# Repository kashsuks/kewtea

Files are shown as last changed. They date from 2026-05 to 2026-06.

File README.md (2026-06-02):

# kewtea
A 30% low profile ortholinear keyboard.

I've recently found that normal keyboards just have too much going on, so it's time to make things simple.



## Bill of Materials

| Name | Quantity | Purpose | Link | Cost (CAD) | Cost (USD) |
|---|---|---|---|---|---|
| Kailh Choc Low Profile Switches (set of 10) | 3 | Switches for the keys | https://typeractive.xyz/products/choc-switches?variant=51038935122151 | 24.00 | 17.40 |
| DO-35 Diodes (set of 50) | 1 | Diodes for the keys grid | https://www.aliexpress.com/item/1005006711895793.html | 3.89 | 2.82 |
| 0.91 Inch 128x32 I2C OLED Display | 1 | OLED display | https://www.aliexpress.com/item/1005008640132638.html | 3.27 | 2.37 |
| Pro Micro NRF52840 | 1 | Cheaper alternative to nice!nano v2 mcu | https://www.aliexpress.com/item/1005009026511947.html | 5.67 | 4.11 |
| MBK Choc Keycaps (set of 10) | 3 | Keycaps needed for the switches | https://typeractive.xyz/products/mbk-keycaps | 15.00 | 10.87 |
| JLCPCB PCB Manufacturing | 1 | The actual pcb board | https://jlcpcb.com/ | N/A | 10.02 |
## Code

I used [kmk](https://github.com/KMKfw/kmk_firmware) along with the circuitpython Nice!nano `.UF2`. They can be used interchangeably with the Pro Micro NRF52840 since it's based off the nice!nano.

The code is yet to be thoroughly tested and will be done so after recieving the board :)

## Schematic



## PCB




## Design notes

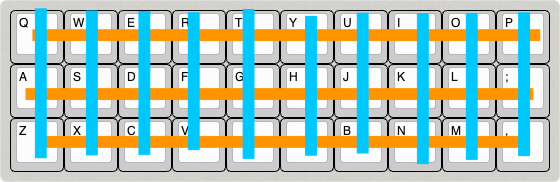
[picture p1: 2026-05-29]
assets/layout.png

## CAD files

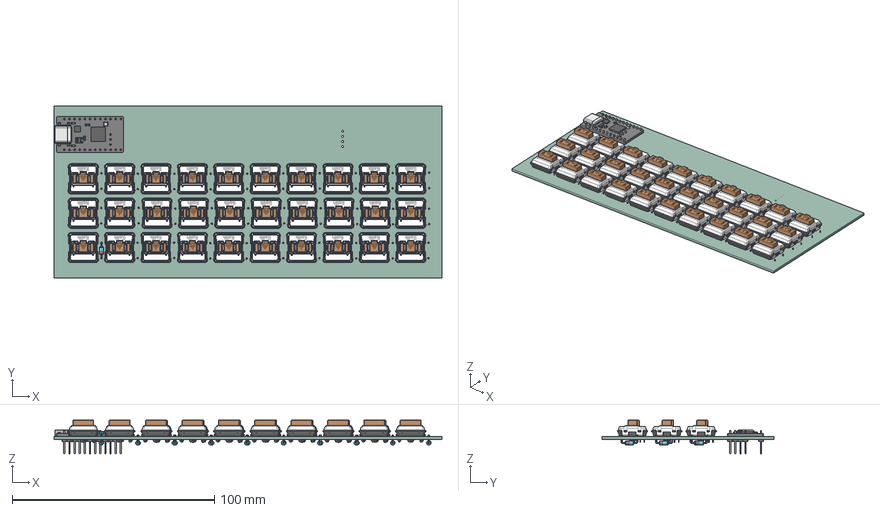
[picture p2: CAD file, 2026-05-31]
kewtea/kewtea.step
192.0 x 85.0 x 16.6 mm
SW_Kailh_Choc_V1_cp x 30
D_DO-35_SOD27_P7.62mm_Horizontal x 30
PinHeader_1x12_P2.54mm_Vertical.step
User Library-TYPE-C-31-M-14.step
MICRO_603 resistor 102
MICRO_stackable header pin x 12
MICRO_stackable header 12
micro_crystal 5x3
MICRO_led
micro_MIC5219
kewtea_PCB

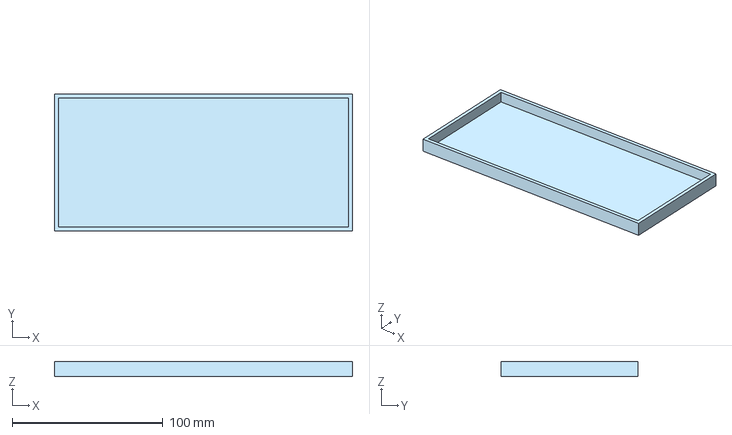
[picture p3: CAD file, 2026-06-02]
production/step/kewtea_case.step
198.0 x 91.0 x 10.0 mm

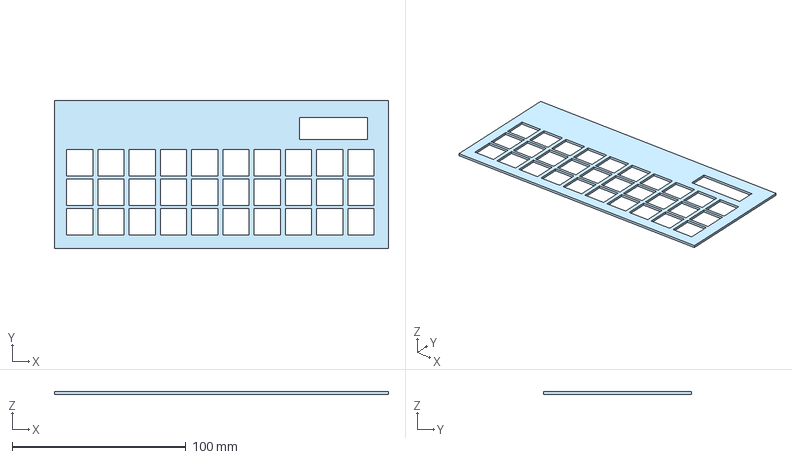
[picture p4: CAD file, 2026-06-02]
production/step/kewtea_plate.step
192.4 x 85.4 x 1.50 mm

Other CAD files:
kewtea/.step
production/stl/kewtea_case.stl
production/stl/kewtea_plate.stl

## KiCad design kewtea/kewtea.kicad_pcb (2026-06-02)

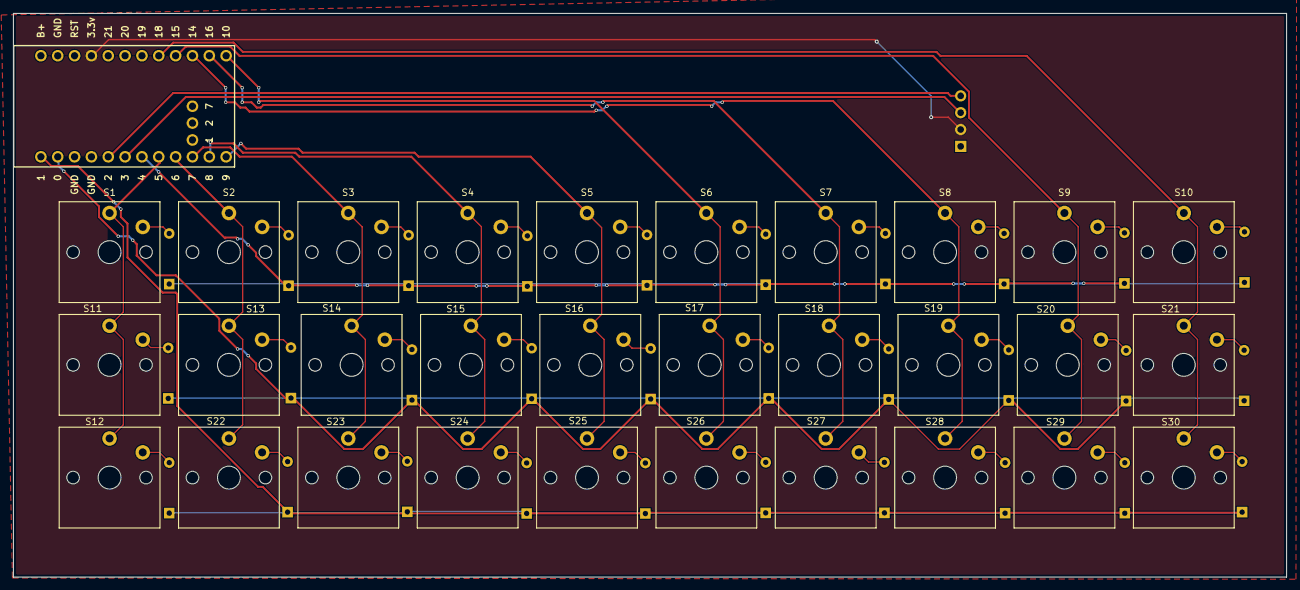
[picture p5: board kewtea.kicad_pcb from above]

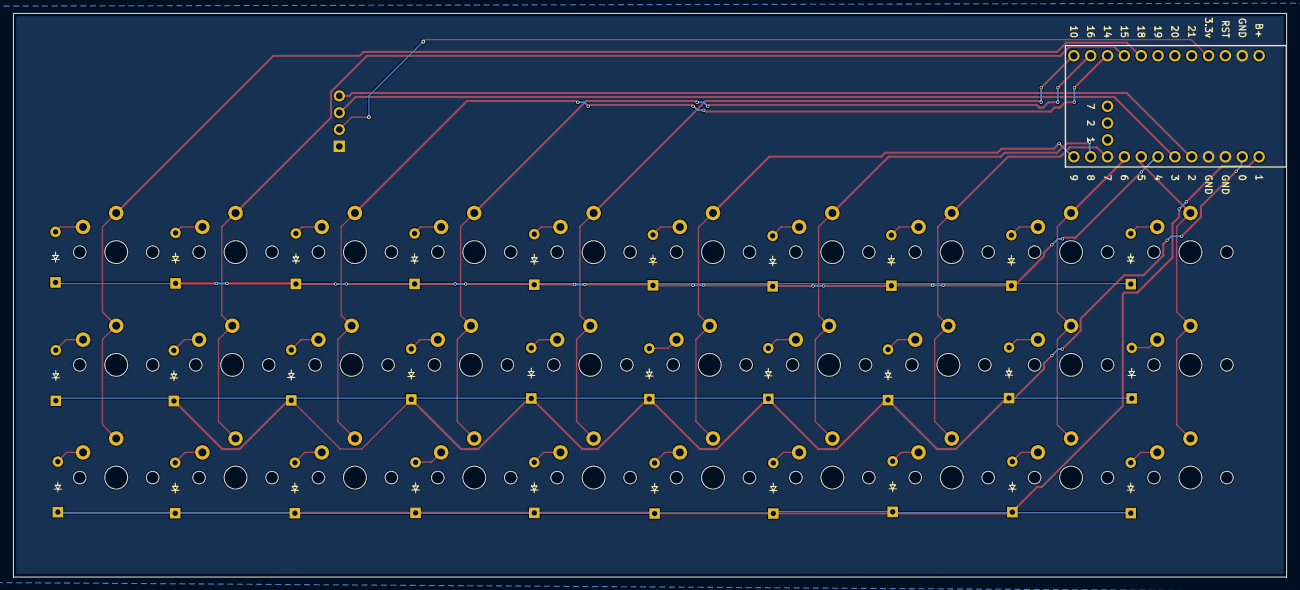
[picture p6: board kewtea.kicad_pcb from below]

Board: 2 copper layers, 192.0 x 85.0 mm, 62 parts (30 on the bottom side), 47 nets.

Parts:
D1, D2, D3, D4, D5, D6, D7, D8, D9, D10, D11, D12, D13, D14, D15, D16, D17, D18, D19, D20, D21, D22, D23, D24, D25, D26, D27, D28, D29, D30: Diode_DO-35
J1: OLED_128x32
S1, S2, S3, S4, S5, S6, S7, S8, S9, S10, S11, S12, S13, S14, S15, S16, S17, S18, S19, S20, S21, S22, S23, S24, S25, S26, S27, S28, S29, S30: Choc_V1
U1: Nice_Nano_V2

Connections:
COL0: S1.1, S11.1, S12.1, U1.8 (5)
COL1: S2.1, S13.1, S22.1, U1.9 (6)
COL2: S3.1, S14.1, S23.1, U1.10 (7)
COL3: S4.1, S15.1, S24.1, U1.11 (8)
COL4: S5.1, S16.1, S25.1, U1.12 (9)
COL5: S6.1, S17.1, S26.1, U1.13 (10)
COL6: S7.1, S18.1, S27.1, U1.14 (16)
COL7: S8.1, S19.1, S28.1, U1.15 (14)
COL8: S9.1, S20.1, S29.1, U1.16 (15)
COL9: S10.1, S21.1, S30.1, U1.17 (18)
GND: J1.1 (GND), U1.3 (GND), U1.4 (GND), U1.23 (GND)
unnamed: D1.2 (A), S1.2
unnamed: D2.2 (A), S2.2
unnamed: D3.2 (A), S3.2
unnamed: D4.2 (A), S4.2
unnamed: D5.2 (A), S5.2
unnamed: D6.2 (A), S6.2
unnamed: D7.2 (A), S7.2
unnamed: D8.2 (A), S8.2
unnamed: D9.2 (A), S9.2
unnamed: D10.2 (A), S10.2
unnamed: D11.2 (A), S11.2
unnamed: D12.2 (A), S12.2
unnamed: D13.2 (A), S13.2
unnamed: D14.2 (A), S14.2
unnamed: D15.2 (A), S15.2
unnamed: D16.2 (A), S16.2
unnamed: D17.2 (A), S17.2
unnamed: D18.2 (A), S18.2
unnamed: D19.2 (A), S19.2
unnamed: D20.2 (A), S20.2
unnamed: D21.2 (A), S21.2
unnamed: D22.2 (A), S22.2
unnamed: D23.2 (A), S23.2
unnamed: D24.2 (A), S24.2
unnamed: D25.2 (A), S25.2
unnamed: D26.2 (A), S26.2
unnamed: D27.2 (A), S27.2
unnamed: D28.2 (A), S28.2
unnamed: D29.2 (A), S29.2
unnamed: D30.2 (A), S30.2
ROW0: D1.1 (K), D2.1 (K), D3.1 (K), D4.1 (K), D5.1 (K), D6.1 (K), D7.1 (K), D8.1 (K), D9.1 (K), D10.1 (K), U1.7 (4)
ROW1: D11.1 (K), D13.1 (K), D14.1 (K), D15.1 (K), D16.1 (K), D17.1 (K), D18.1 (K), D19.1 (K), D20.1 (K), D21.1 (K), U1.2 (0)
ROW2: D12.1 (K), D22.1 (K), D23.1 (K), D24.1 (K), D25.1 (K), D26.1 (K), D27.1 (K), D28.1 (K), D29.1 (K), D30.1 (K), U1.1
SCL: J1.3 (SCL), U1.6 (3)
SDA: J1.4 (SDA), U1.5 (2)
VCC: J1.2 (VCC), U1.21 (3.3v)

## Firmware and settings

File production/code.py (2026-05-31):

"""
code.py — KMK firmware entry point for the kewtea keyboard.

Targets a Pro Micro NRF52840 (nice!nano-compatible) running CircuitPython.
Defines the 3×10 key matrix, single-layer QWERTY keymap, and an SSD1306
OLED that displays elapsed uptime. No build step required — edit this file
directly on the CIRCUITPY USB drive and the changes take effect on save.

Required libraries (copy to CIRCUITPY/lib/ from the Adafruit bundle):
  - adafruit_displayio_ssd1306
  - adafruit_display_text
"""

import time
import busio
import displayio
import terminalio
import microcontroller
from adafruit_display_text import label
import adafruit_displayio_ssd1306

from kmk.kmk_keyboard import KMKKeyboard
from kmk.keys import KC
from kmk.scanners import DiodeOrientation


# ── Display ───────────────────────────────────────────────────────────────────

displayio.release_displays()

_i2c = busio.I2C(
    scl=microcontroller.pin.P0_20,  # header pin 6
    sda=microcontroller.pin.P0_17,  # header pin 5
)
_bus = displayio.I2CDisplay(_i2c, device_address=0x3C)
_display = adafruit_displayio_ssd1306.SSD1306(_bus, width=128, height=32)

_root = displayio.Group()
_display.root_group = _root

_time_label = label.Label(
    terminalio.FONT,
    text='00:00:00',
    color=0xFFFFFF,
    x=32,
    y=15,
)
_root.append(_time_label)

_boot_time = time.monotonic()


# ── Uptime extension ──────────────────────────────────────────────────────────

class UptimeDisplay:
    """KMK extension that refreshes the OLED with elapsed uptime once per second.

    Uses the board's monotonic clock rather than wall-clock time because no
    hardware RTC is present. Replace _render with an RTC read when one is added.

    Attributes:
        _label: The displayio Label updated each tick.
        _last_tick: Monotonic timestamp of the last display update.
    """

    def __init__(self, time_label: label.Label) -> None:
        """
        Args:
            time_label: Label widget whose text is overwritten each second.
        """
        self._label = time_label
        self._last_tick = 0.0

    def _render(self) -> None:
        """Formats elapsed seconds as HH:MM:SS and pushes it to the label."""
        elapsed = int(time.monotonic() - _boot_time)
        h = elapsed // 3600
        m = (elapsed % 3600) // 60
        s = elapsed % 60
        self._label.text = f'{h:02d}:{m:02d}:{s:02d}'

    def during_bootup(self, keyboard: KMKKeyboard) -> None:
        pass

    def before_matrix_scan(self, keyboard: KMKKeyboard) -> None:
        """Called each scan cycle — throttled to one display update per second."""
        now = time.monotonic()
        if now - self._last_tick >= 1.0:
            self._last_tick = now
            self._render()

    def after_matrix_scan(self, keyboard: KMKKeyboard) -> None:
        pass

    def before_hid_send(self, keyboard: KMKKeyboard) -> None:
        pass

    def after_hid_send(self, keyboard: KMKKeyboard) -> None:
        pass

    def on_powersave_enable(self, keyboard: KMKKeyboard) -> None:
        pass

    def on_powersave_disable(self, keyboard: KMKKeyboard) -> None:
        pass


# ── Keyboard ──────────────────────────────────────────────────────────────────

keyboard = KMKKeyboard()

keyboard.row_pins = (
    microcontroller.pin.P0_04,  # ROW0 — Q..P
    microcontroller.pin.P0_00,  # ROW1 — A..SEMI
    microcontroller.pin.P0_01,  # ROW2 — Z..DOT
)

keyboard.col_pins = (
    microcontroller.pin.P0_05,  # COL0
    microcontroller.pin.P0_06,  # COL1
    microcontroller.pin.P0_07,  # COL2
    microcontroller.pin.P0_08,  # COL3
    microcontroller.pin.P0_09,  # COL4
    microcontroller.pin.P0_10,  # COL5
    microcontroller.pin.P0_13,  # COL6
    microcontroller.pin.P0_14,  # COL7
    microcontroller.pin.P0_15,  # COL8
    microcontroller.pin.P0_16,  # COL9
)

keyboard.diode_orientation = DiodeOrientation.ROW2COL

keyboard.extensions.append(UptimeDisplay(_time_label))

keyboard.keymap = [
    [
        KC.Q,    KC.W,    KC.E,    KC.R,    KC.T,
        KC.Y,    KC.U,    KC.I,    KC.O,    KC.P,

        KC.A,    KC.S,    KC.D,    KC.F,    KC.G,
        KC.H,    KC.J,    KC.K,    KC.L,    KC.SCLN,

        KC.Z,    KC.X,    KC.C,    KC.V,    KC.SPC,
        KC.B,    KC.N,    KC.M,    KC.COMM, KC.DOT,
    ]
]

if __name__ == '__main__':
    keyboard.go()

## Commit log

2026-05-29 add schematic with section outlines
    [kewtea.kicad_pcb, kewtea.kicad_sch]
2026-05-29 add pcb with 3d renders
    [kewtea.kicad_pcb, kewtea.kicad_sch]
2026-05-29 add generated drill files for pcb
    [kewtea.kicad_pcb]
2026-05-30 fix pcb zone fill issues
    [kewtea.kicad_pcb]
2026-05-30 fix unrouted vcc from nice!nano to 128x32 oled
    [kewtea.kicad_pcb]
2026-05-30 fix silkscreen and bad routing
    [kewtea.kicad_pcb]
2026-05-31 update dimensions for pcb
    [.step, kewtea.kicad_pcb, kewtea.step]
2026-05-31 create bom file
2026-05-31 add bom with parts for now (need to add m2 screws after modelling)
    [BOM.csv]
2026-05-31 feat: add ZMK shield for kewtea 30% ortholinear keyboard
    Implements the full ZMK user-config structure targeting nice_nano_v2:
    - 3×10 GPIO matrix (row2col, all pins on P0)
    - SSD1306 128×32 OLED over I2C0 (SDA=P0.17, SCL=P0.20)
    - Single-layer QWERTY keymap with space at ROW2/COL4
    - Custom status screen displaying uptime as HH:MM:SS
2026-05-31 kicad lock files
2026-05-31 ci: replace reusable workflow with explicit build steps
    ZMK's reusable workflow expects build.yaml at the repo root, but
    this repo nests firmware under code/ alongside KiCad hardware files.
    The explicit workflow passes the correct config path to west and
    west build directly.
2026-05-31 fix: use nice_nano/v2 board name for Zephyr 4.x hardware model
    Zephyr 3.5+ replaced underscore-separated board variants with slash
    notation. nice_nano_v2 is now nice_nano/v2 in the new hardware model
    used by the zmk-build-arm:stable container (Zephyr 4.1.0).
2026-05-31 feat: replace ZMK with KMK firmware
    KMK runs on CircuitPython — no build system or compilation needed.
    Edit code/code.py directly on the CIRCUITPY USB drive.
    - 3x10 GPIO matrix via microcontroller.pin (P0.xx notation)
    - SSD1306 128x32 OLED over I2C showing uptime as HH:MM:SS
    - CI reduced to a Python syntax check
    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
    [code.py]
2026-06-02 pcb with dimensions
    [kewtea.kicad_pcb]
2026-06-02 add the production cad files
    [kewtea_case.step, kewtea_case.stl, kewtea_plate.step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]
2026-06-02 removed dimensions and made zone fill smaller
    [kewtea.kicad_pcb]
